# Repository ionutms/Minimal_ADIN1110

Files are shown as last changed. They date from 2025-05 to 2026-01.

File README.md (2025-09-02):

# Minimal_ADIN1110

## Overview

This repository contains a minimal KiCad design project for the Analog Devices ADIN1110, a robust, industrial, low-power 10BASE-T1L Ethernet MAC-PHY. The project is designed for industrial Ethernet applications and complies with the IEEE® 802.3cg-2019™ standard for long-reach, 10 Mbps Single Pair Ethernet (SPE).

## Disclaimer

> [!NOTE]
> This project is provided "as is" and without any warranty, express or implied. For more details, please see the [LICENSE](LICENSE) file.

## About the ADIN1110

The ADIN1110 from Analog Devices is a fully integrated and featured low-power 10BASE-T1L MAC-PHY. It is designed for use in industrial Ethernet applications and connects to a host controller via a 4-wire Serial Peripheral Interface (SPI). This allows for the use of lower-power processors without an integrated MAC, which helps to reduce overall system power consumption.

Key features include:

- **Integrated MAC and SPI Interface:** The ADIN1110 includes an integrated Media Access Control (MAC) that allows for direct connection to a host controller via a 4-wire Serial Peripheral Interface (SPI). This enables the use of lower-power processors without an integrated MAC, contributing to lower overall system power consumption.
- **Low Power Consumption:** The device features low power consumption, listed as 42 mW in a typical dual-supply scenario.
- **Long Cable Reach:** It supports a cable reach of up to 1700 meters.
- **Intrinsic Safety Support:** The ADIN1110 is suitable for intrinsic safety applications due to programmable transmit levels, external termination resistors, and independent receive and transmit pins.
- **Robustness:** It integrates voltage supply monitoring and power-on reset (POR) circuitry to enhance system-level robustness.
- **Package:** The ADIN1110 is available in a 40-lead, 6 mm × 6 mm Lead Frame Chip Scale Package (LFCSP).
- **Wide Temperature Range:** It operates over a wide temperature range of -40°C to +105°C.

## Project Structure

```
minimal_adin1110/
├── minimal_adin1110.kicad_sch       # Main schematic file
├── minimal_adin1110.kicad_pcb       # PCB layout file
├── minimal_adin1110.kicad_pro       # Project configuration file
├── fp-lib-table                     # Footprint library table
├── sym-lib-table                    # Symbol library table
├── project_jobs_set.kicad_jobset    # Project job settings
├── ibom.config.ini                  # Interactive BOM configuration
├── docs/                            # Documentation files
│   ├── pictures/                    # Images and photos
│   ├── schematics/                  # Schematic PDF exports
│   └── 3d_models/                   # 3D model files
└── KiCAD_Symbols_Generator/         # Submodule for symbol generation from CSV data
```

## Project Features

This design provides a minimal implementation of the ADIN1110 with the following features:

- **Power Supply:**
  - VIN: +3.3V
- **Channel Configuration:**
  - Basic protection circuits for the Ethernet twisted pair.
- **Bill of Materials (BOM):**
  - Interactive HTML BOM (`ibom.html`) for easy component identification and sourcing.
- **Libraries:**
  - Comprehensive symbol and footprint libraries integrated as a submodule.
- **3D Model:**
  - Includes a 3D model of the board for better visualization.

## Getting Started

### Prerequisites

- [KiCad EDA](https://www.kicad.org/) version 9.0 or later installed on your system
- Git (for cloning the repository and submodule management)

### Opening the Project

1. **Clone the repository** (including submodules):
   ```bash
   git clone --recursive https://github.com/ionutms/Minimal_ADIN1110.git
   ```
   
   If you've already cloned the repository without submodules, initialize them with:
   ```bash
   git submodule init
   git submodule update
   ```

2. **Open the project in KiCad**:
   - Launch KiCad
   - Click "Open Existing Project"
   - Navigate to the cloned repository folder
   - Select the `minimal_adin1110.kicad_pro` file

3. **Explore the design**:
   - Open the schematic editor to view the circuit design
   - Open the PCB editor to view the board layout
   - Review the symbol and footprint libraries used in the design

### Project Files

- **Main schematic**: `minimal_adin1110.kicad_sch` - Contains the primary circuit design with the ADIN1110 and support components
- **PCB layout**: `minimal_adin1110.kicad_pcb` - Physical board design file with proper component placement
- **Project configuration**: `minimal_adin1110.kicad_pro` - KiCad project settings

## Dependencies

This project has the following dependencies:

### 1. KiCAD Symbols Generator

This repository uses [KiCAD_Symbols_Generator](https://github.com/ionutms/KiCAD_Symbols_Generator) as a submodule for custom symbol generation.

To initialize the submodule after cloning this repository:

```bash
git submodule update --init --recursive
```

### 2. 3D Models

This project requires the [3D_Models_Vault](https://github.com/ionutms/3D_Models_Vault) repository for 3D models.

#### Setup for KiCAD 9:

1. Clone the 3D models repository:
   ```bash
   git clone https://github.com/ionutms/3D_Models_Vault.git
   ```

2. In KiCAD 9, add an environment variable:
   - Variable name: `KICAD9_3D_MODELS_VAULT`
   - Variable value: Full path to where you cloned the 3D_Models_Vault repository

## Usage

After setting up the dependencies, open the project in KiCAD 9 to access all features including the 3D models.

## Symbol Generator Submodule

This project includes the KiCAD_Symbols_Generator as a submodule, which provides tools for generating KiCad symbols from CSV data files. For more information on using this tool, see the [KiCAD_Symbols_Generator documentation](minimal_adin1110/KiCAD_Symbols_Generator/README.md).

## Documentation

The `docs` folder contains:
- Schematic PDF exports
- Images and photos of the design
- 3D model files (GLB and WRL formats)

## Visuals

The following images showcase the PCB design from different perspectives:

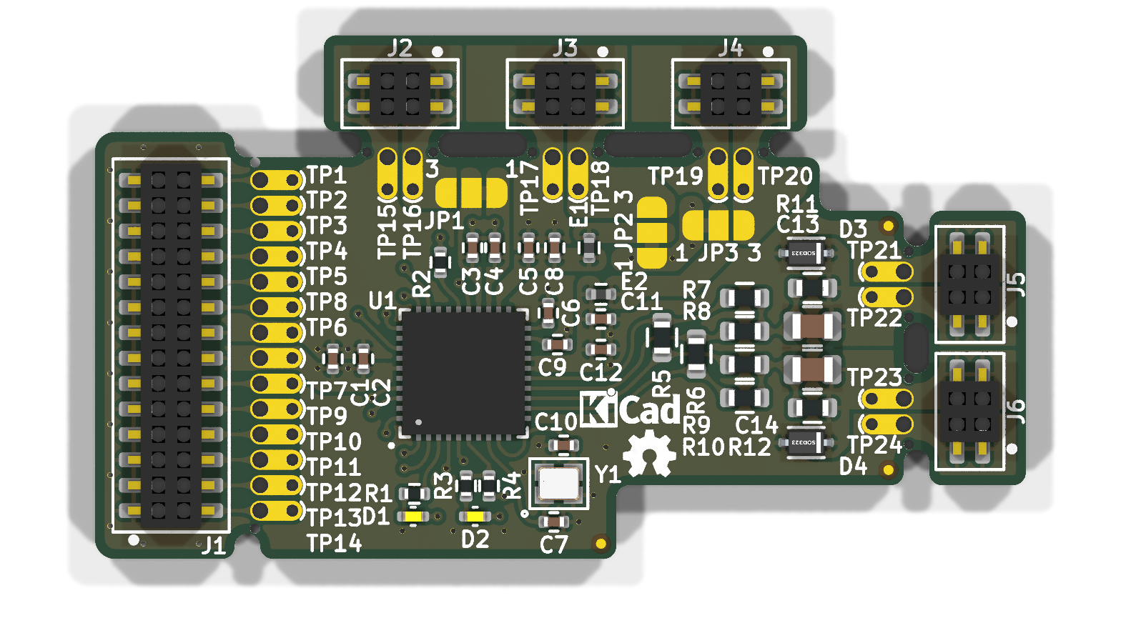
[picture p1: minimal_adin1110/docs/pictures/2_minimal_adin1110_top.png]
Top View

*Top View of the PCB*

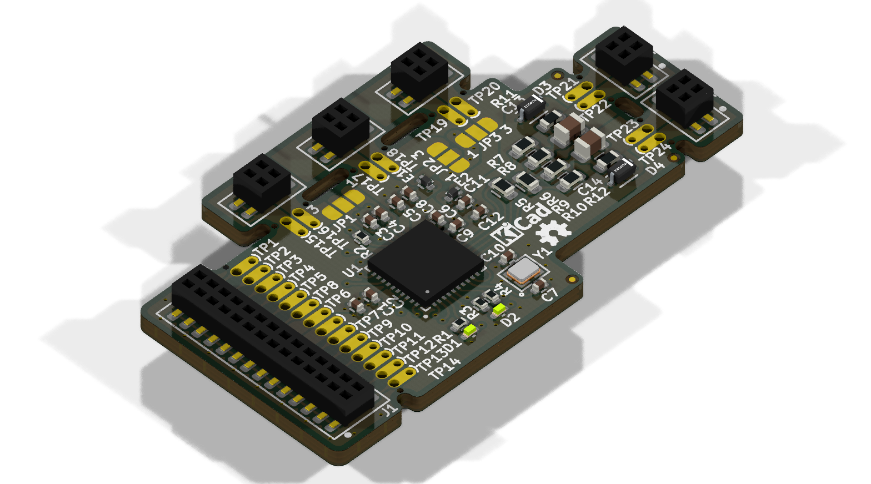
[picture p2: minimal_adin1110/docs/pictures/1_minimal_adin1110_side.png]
Side View

*Side View of the PCB*

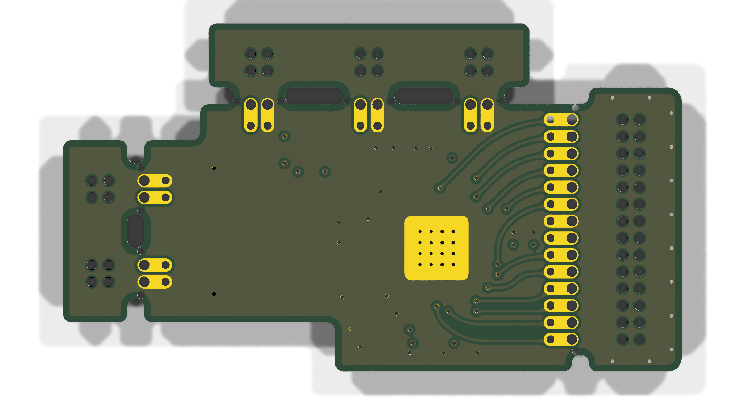
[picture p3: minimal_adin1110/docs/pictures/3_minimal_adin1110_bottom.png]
Bottom View

*Bottom View of the PCB*

## License

This project is licensed under the MIT License - see the [LICENSE](LICENSE) file for details.

## References

- [ADIN1110 Datasheet](https://www.analog.com/media/en/technical-documentation/data-sheets/adin1110.pdf)
- [KiCad EDA](https://www.kicad.org/)

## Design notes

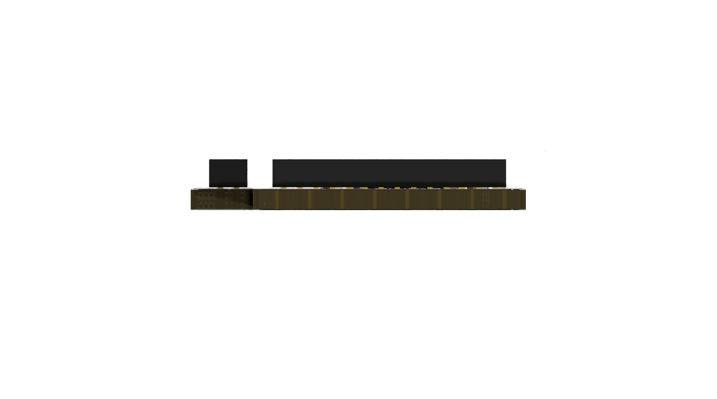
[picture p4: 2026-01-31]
minimal_adin1110/docs/pictures/4_minimal_adin1110_left.png

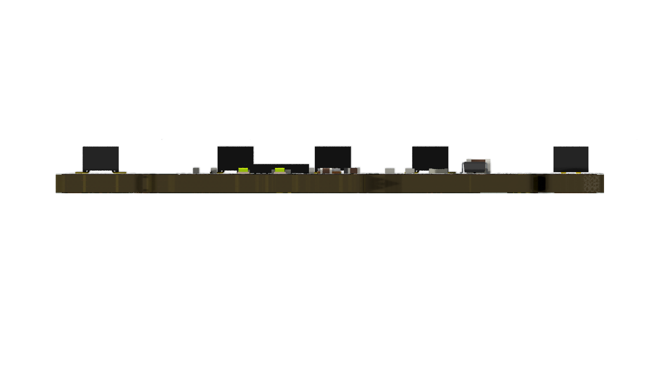
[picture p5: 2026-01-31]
minimal_adin1110/docs/pictures/6_minimal_adin1110_front.png

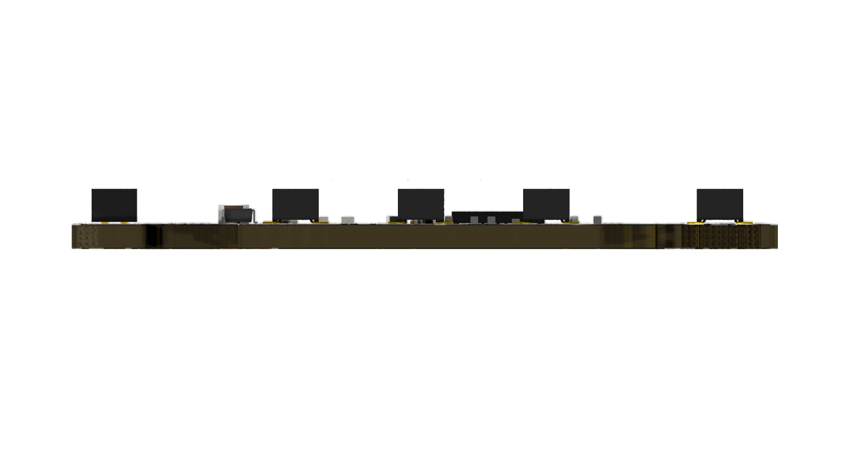
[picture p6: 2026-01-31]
minimal_adin1110/docs/pictures/7_minimal_adin1110_back.png

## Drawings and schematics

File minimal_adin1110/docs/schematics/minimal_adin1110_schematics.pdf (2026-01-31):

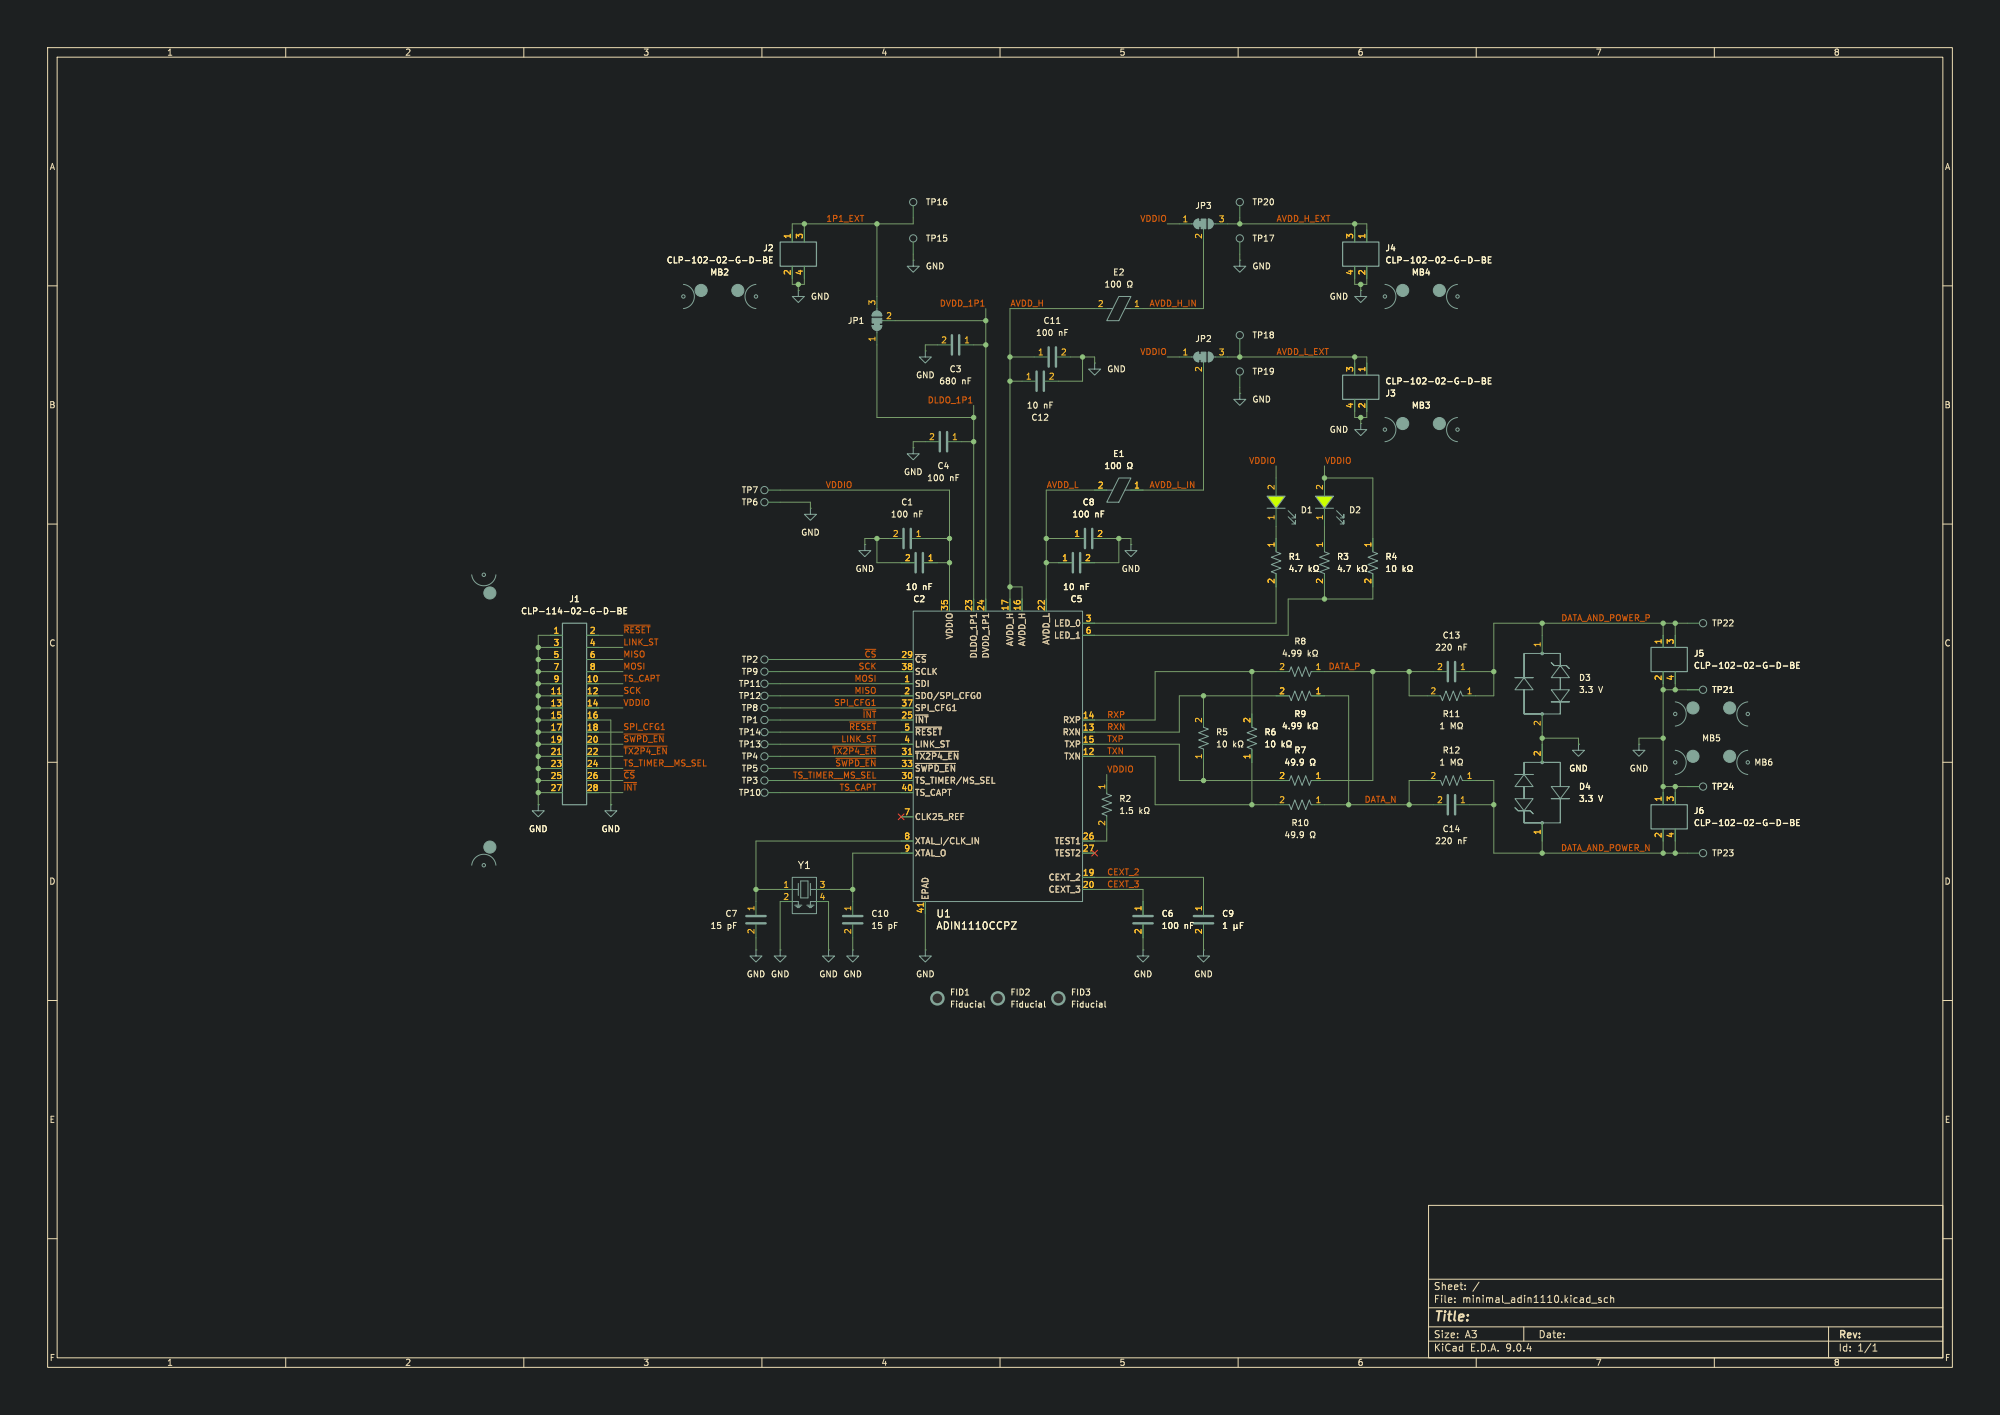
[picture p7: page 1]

Id: 1/1 Title: File: minimal_adin1110.kicad_sch Sheet: /

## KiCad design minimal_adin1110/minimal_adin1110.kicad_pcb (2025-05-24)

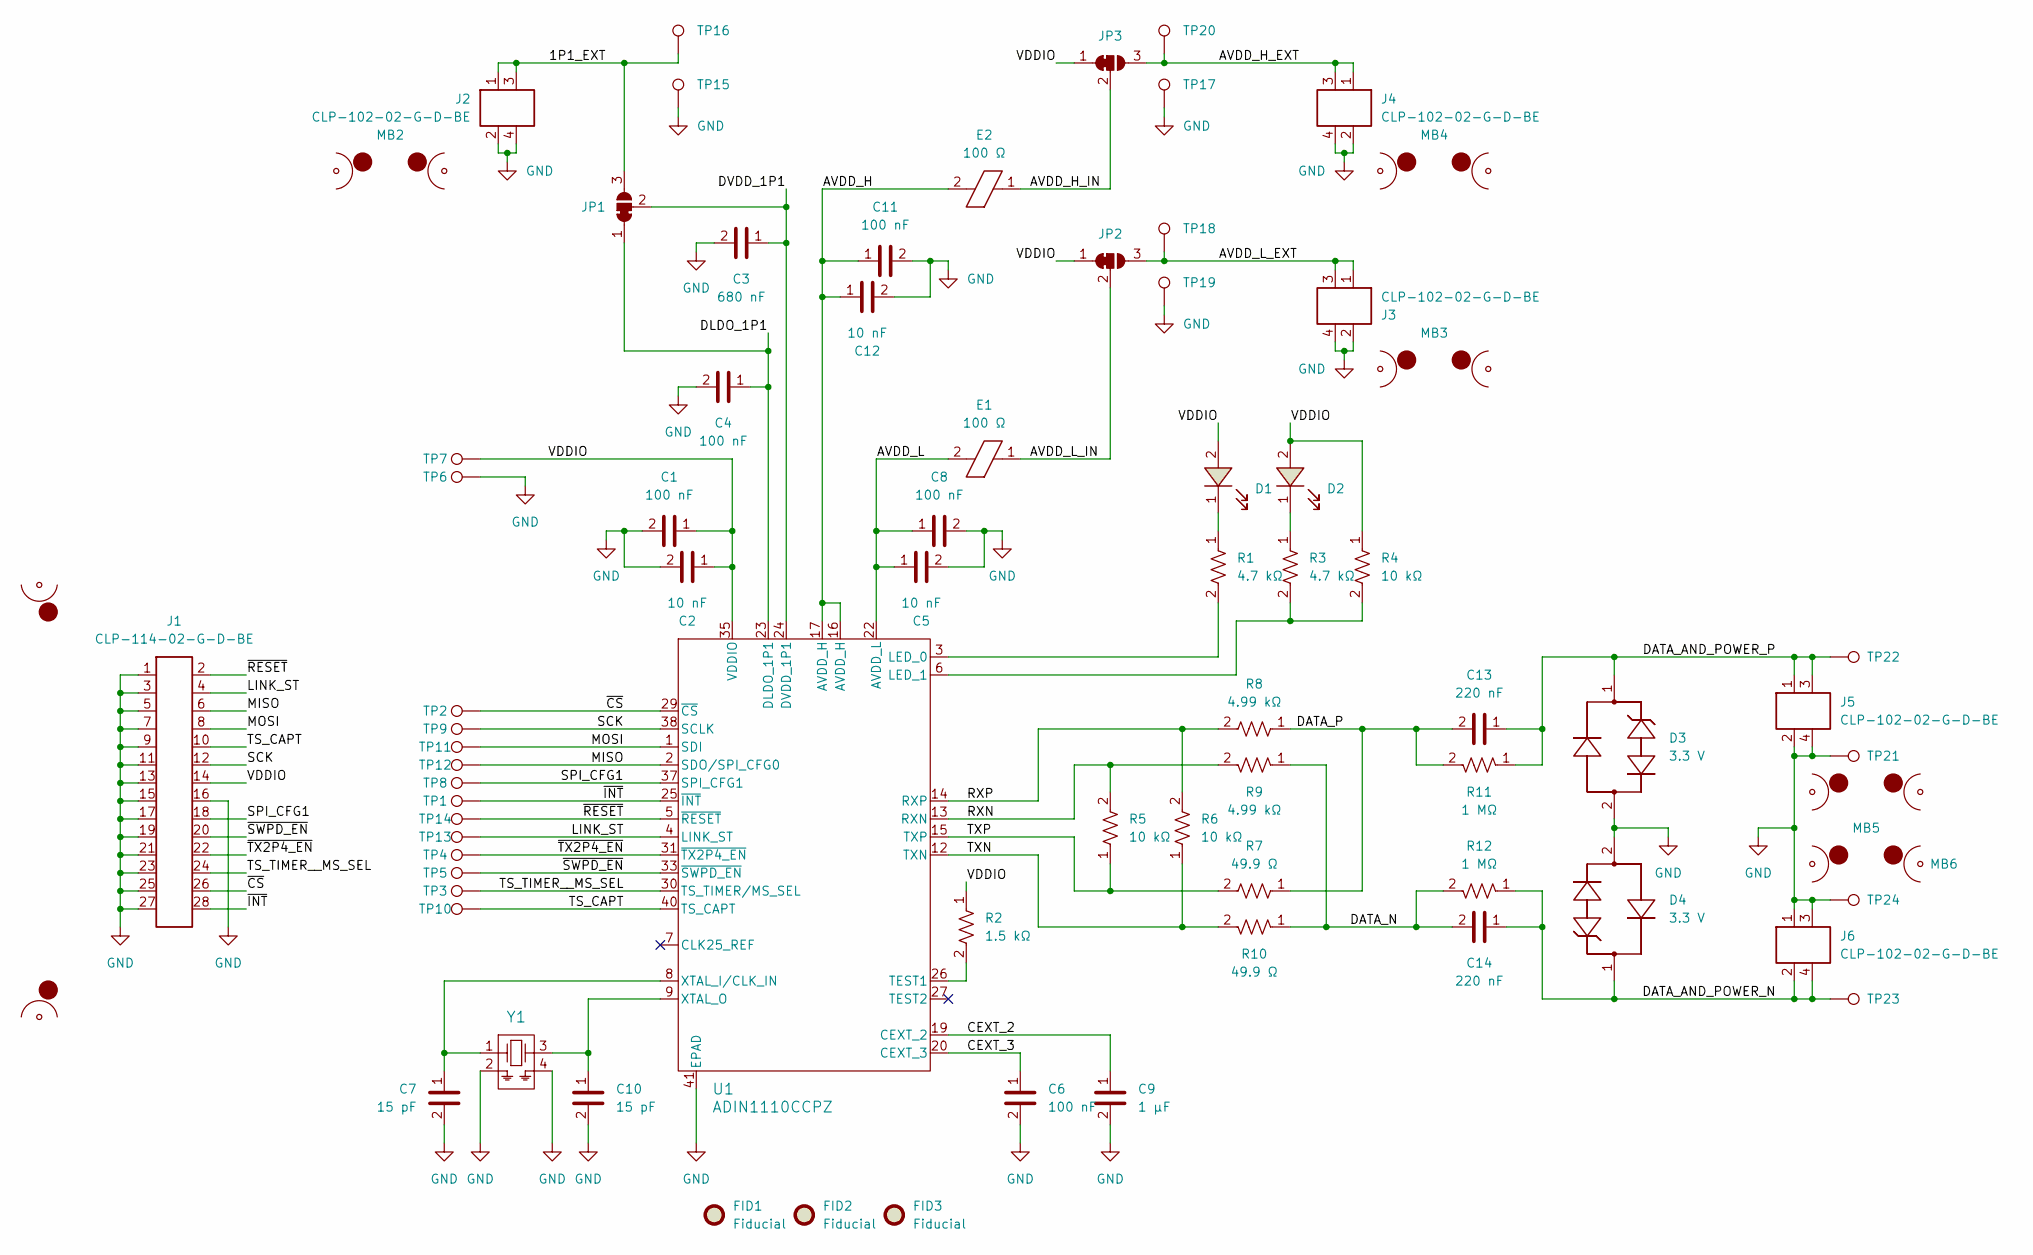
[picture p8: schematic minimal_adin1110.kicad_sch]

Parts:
C1, C4, C6, C8, C11: 100 nF; C_0402_1005Metric; Voltage Rating DC 50 VDC; Tolerance 10%; MPN GCM155R71H104KE02D
C2, C5, C12: 10 nF; C_0402_1005Metric; Voltage Rating DC 100 VDC; Tolerance 10%; MPN C1005X7S2A103K050BB
C3: 680 nF; C_0402_1005Metric; Voltage Rating DC 10 VDC; Tolerance 10%; MPN GCM155C71A684KE38D
C7, C10: 15 pF; C_0402_1005Metric; Voltage Rating DC 50 VDC; Tolerance 1%; MPN GCM1555C1H150FA16D
C9: 1 µF; C_0402_1005Metric; Voltage Rating DC 16 VDC; Tolerance 10%; MPN C1005X6S1C105K050BC
C13, C14: 220 nF; C_0805_2012Metric; Voltage Rating DC 16 VDC; Tolerance 5%; MPN C0805C224J1RACTU
D1, D2: 1.8 V; LED_GREEN_0402_1005Metric; MPN APHHS1005CGCK
D3, D4: 3.3 V; SOD323; MPN SP4020-01FTG
E1, E2: 100 Ω; 742792731; Tolerance ±25%; MPN 742792731
FID1, FID2, FID3: Fiducial; Fiducial_0.5mm_Mask1mm
J1: CLP-114-02-G-D-BE; Current Rating (A) 5.2; Voltage Rating (V) 300; MPN CLP-114-02-G-D-BE
J2, J3, J4, J5, J6: CLP-102-02-G-D-BE; Current Rating (A) 5.2; Voltage Rating (V) 300; MPN CLP-102-02-G-D-BE
JP1, JP2, JP3: SolderJumper_3_Open; SolderJumper-3_P1.3mm_Bridged_1_2_RoundedPad1.0x1.5mm_Numbe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
MB1: mouse-bite-midle-50mil-200mil; mouse-bite-50mil-790mil
MB2, MB3, MB4, MB5, MB6: mouse-bite-midle-50mil-200mil
R1, R3: 4.7 kΩ; R_0402_1005Metric; Voltage Rating 50V; Tolerance 5%; MPN ERJ-2GEJ472X
R2: 1.5 kΩ; R_0402_1005Metric; Voltage Rating 50V; Tolerance 1%; MPN ERJ-2RKF1501X
R4: 10 kΩ; R_0402_1005Metric; Voltage Rating 50V; Tolerance 1%; MPN ERJ-2RKF1002X
R5, R6: 10 kΩ; R_0603_1608Metric; Voltage Rating 75V; Tolerance 1%; MPN ERJ-3EKF1002V
R7, R10: 49.9 Ω; R_0603_1608Metric; Voltage Rating 75V; Tolerance 1%; MPN ERJ-3EKF49R9V
R8, R9: 4.99 kΩ; R_0603_1608Metric; Voltage Rating 75V; Tolerance 1%; MPN ERJ-3EKF4991V
R11, R12: 1 MΩ; R_0603_1608Metric; Voltage Rating 75V; Tolerance 1%; MPN ERJ-3EKF1004V
TP1, TP2, TP3, TP4, TP5, TP6, TP7, TP8, TP9, TP10, TP11, TP12, TP13, TP14, TP15, TP16, TP17, TP18, TP19, TP20, TP21, TP22, TP23, TP24: TestPoint; TestPoint_THTPad_Castelated
U1: ADIN1110CCPZ; CP-40-29_ADI; MPN ADIN1110CCPZ
Y1: 25.0000MHz; SO4_FA-128_2p0x1p6_SEC

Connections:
/1P1_EXT: J2.1, J2.3, JP1.3 (B), TP16.1
/AVDD_H: C11.1, C12.1, E2.2, U1.16 (AVDD_H), U1.17 (AVDD_H)
/AVDD_H_EXT: J4.1, J4.3, JP3.3 (B), TP20.1
/AVDD_H_IN: E2.1, JP3.2 (C)
/AVDD_L: C5.1, C8.1, E1.2, U1.22 (AVDD_L)
/AVDD_L_EXT: J3.1, J3.3, JP2.3 (B), TP18.1
/AVDD_L_IN: E1.1, JP2.2 (C)
/CEXT_2: C9.1, U1.19 (CEXT_2)
/CEXT_3: C6.1, U1.20 (CEXT_3)
/DATA_AND_POWER_N: C14.1, D4.1, J6.2, J6.4, R12.1, TP23.1
/DATA_AND_POWER_P: C13.1, D3.1, J5.1, J5.3, R11.1, TP22.1
/DATA_N: C14.2, R9.1, R10.1, R12.2
/DATA_P: C13.2, R7.1, R8.1, R11.2
/DLDO_1P1: C4.1, JP1.1 (A), U1.23 (DLDO_1P1)
/DVDD_1P1: C3.1, JP1.2 (C), U1.24 (DVDD_1P1)
/LINK_ST: J1.4, TP13.1, U1.4 (LINK_ST)
/MISO: J1.6, TP12.1, U1.2 (SDO/SPI_CFG0)
/MOSI: J1.8, TP11.1, U1.1 (SDI)
/RXN: R5.2, R9.2, U1.13 (RXN)
/RXP: R6.2, R8.2, U1.14 (RXP)
/SCK: J1.12, TP9.1, U1.38 (SCLK)
/SPI_CFG1: J1.18, TP8.1, U1.37 (SPI_CFG1)
/TS_CAPT: J1.10, TP10.1, U1.40 (TS_CAPT)
/TS_TIMER__MS_SEL: J1.24, TP3.1, U1.30 (TS_TIMER/MS_SEL)
/TXN: R6.1, R10.2, U1.12 (TXN)
/TXP: R5.1, R7.2, U1.15 (TXP)
/VDDIO: C1.1, C2.1, D1.2, D2.2, J1.14, JP2.1 (A), JP3.1 (A), R2.1, R4.1, TP7.1, U1.35 (VDDIO)
/~CS: J1.26, TP2.1, U1.29 (~CS)
/~INT: J1.28, TP1.1, U1.25 (~INT)
/~RESET: J1.2, TP14.1, U1.5 (~RESET)
/~SWPD_EN: J1.20, TP5.1, U1.33 (~SWPD_EN)
/~TX2P4_EN: J1.22, TP4.1, U1.31 (~TX2P4_EN)
GND: C1.2, C2.2, C3.2, C4.2, C5.2, C6.2, C7.2, C8.2, C9.2, C10.2, C11.2, C12.2, D3.2, D4.2, J1.1, J1.3, J1.5, J1.7, J1.9, J1.11, J1.13, J1.15, J1.16, J1.17, J1.19, J1.21, J1.23, J1.25, J1.27, J2.2, J2.4, J3.2, J3.4, J4.2, J4.4, J5.2, J5.4, J6.1, J6.3, TP6.1, TP15.1, TP17.1, TP19.1, TP21.1, TP24.1, U1.41 (EPAD), Y1.2, Y1.4
unnamed: D1.1, R1.1
unnamed: D2.1, R3.1
unnamed: R1.2, U1.3 (LED_0)
unnamed: R3.2, R4.2, U1.6 (LED_1)
unnamed: R2.2, U1.26 (TEST1)
unnamed: C7.1, U1.8 (XTAL_I/CLK_IN), Y1.1
unnamed: C10.1, U1.9 (XTAL_O), Y1.3

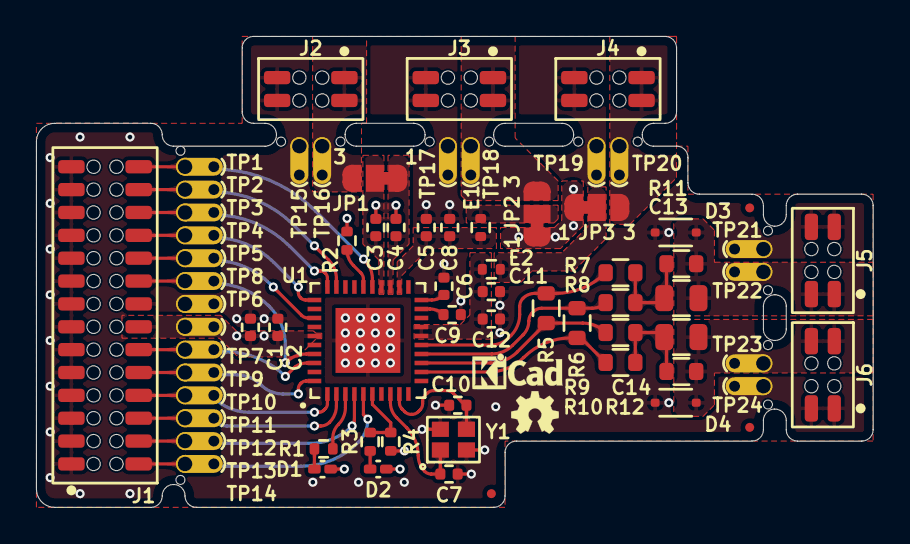
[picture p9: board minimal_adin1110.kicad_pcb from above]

Board: 4 copper layers, 46.5 x 26.2 mm, 76 parts (0 on the bottom side), 40 nets.

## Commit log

2025-02-03 Add initial KiCad project files for minimal_adin1110
    [minimal_adin1110.kicad_pcb, minimal_adin1110.kicad_sch]
2025-02-03 Add submodule for KiCAD Symbol Generator
2025-02-04 Update KiCAD Symbol Generator submodule and add symbol and footprint library tables
    [minimal_adin1110.kicad_pcb, minimal_adin1110.kicad_sch]
2025-02-05 Add schematic PDF for minimal_adin1110 project
2025-02-05 Add VRML file reference for minimal_adin1110 project
    [minimal_adin1110.kicad_pcb, minimal_adin1110.kicad_sch]
2025-02-07 Add UNITED_MOUSE_BITES_DATA_BASE library to sym-lib-table
    [minimal_adin1110.kicad_pcb, minimal_adin1110.kicad_sch]
2025-02-12 Minor changes
    [minimal_adin1110.kicad_pcb]
2025-02-28 Update component blacklist and add new libraries to symbol and footprint tables
    [minimal_adin1110.kicad_pcb, minimal_adin1110.kicad_sch]
2025-03-07 Update subproject commit for KiCAD Symbol Generator
    [minimal_adin1110.kicad_pcb, minimal_adin1110.kicad_sch]
2025-03-08 Update KiCAD subproject commit and adjust pad dimensions
    [minimal_adin1110.kicad_pcb, minimal_adin1110.kicad_sch]
2025-03-14 Update minimal_adin1110 GLB file
    [minimal_adin1110.kicad_pcb]
2025-03-16 Remove KiCAD Symbol Generator submodule and associated configuration
2025-03-16 Add KiCAD Symbols Generator submodule and configuration
2025-03-16 Update minimal_adin1110 configuration and library paths for KiCAD Symbols Generator
    [minimal_adin1110.kicad_pcb]
2025-03-18 Switch to KiCad 9
    [minimal_adin1110.kicad_pcb, minimal_adin1110.kicad_sch]
2025-03-20 Update subproject reference for KiCAD Symbols Generator
2025-03-20 Add new assets and update project configuration for minimal_adin1110
    [minimal_adin1110.kicad_pcb]
2025-04-11 development backup
    [minimal_adin1110.kicad_pcb, minimal_adin1110.kicad_sch]
2025-04-11 Revert "development backup"
    This reverts commit 9283c747e1c3676efe85313f236ce4507e137f4e.
    [minimal_adin1110.kicad_pcb, minimal_adin1110.kicad_sch]
2025-04-15 Update subproject commit reference for KiCAD Symbols Generator
2025-04-17 Update KiCad documentation (schematics and PCB renders)
2025-04-18 Update Docker image for KiCad in workflow to version 9.0
2025-04-18 Update Docker image in workflow and remove obsolete schematic and image files for minimal_adin1110
2025-04-18 Update Docker image for KiCad to version 9.0 in workflow
2025-04-18 Update subproject commit for KiCAD Symbols Generator
2025-04-18 Update trigger branch for KiCad documentation generation workflow
2025-04-18 Enhance GitHub Actions workflow for KiCad documentation generation by adding permissions, improving branch handling, and ensuring proper output restoration and commit processes.
2025-04-18 Update GitHub Actions workflow for KiCad documentation generation
2025-04-18 Add zoom factor input for PCB 3D view rendering in workflow
2025-04-18 Refactor zoom factor handling in PCB 3D view rendering step
2025-04-18 Refactor zoom factor handling in KiCad job workflow to use environment variable
2025-04-18 Update default zoom factor in KiCad job workflow and simplify zoom factor handling
2025-04-24 Refactor workflow to improve handling of KiCad project files and outputs
2025-04-24 Update KiCad documentation for minimal_adin1110 (schematics and PCB renders)
2025-04-24 Add detailed view configuration to KiCad settings
2025-04-24 Remove obsolete schematic and image files for minimal_adin1110
2025-04-24 Update KiCad configuration for improved view settings
2025-04-24 Update KiCad configuration for side view settings
2025-05-24 Add GitHub Actions workflow to generate KiCad 3D models
2025-05-25 Update workflow trigger branch for KiCad 3D models generation
2025-08-18 Add bottom view rendering support to KiCad workflow
2025-08-22 Update GitHub workflow files for KiCad jobs and 3D models
2025-08-29 Update GitHub workflows for KiCad models and jobs
2025-10-05 chore: update workflows and kicad config from central repository
2025-10-26 Update kicad-config workflow settings
